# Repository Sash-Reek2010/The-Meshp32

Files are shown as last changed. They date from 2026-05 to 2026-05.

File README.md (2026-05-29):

# The Meshp32
An ESP32 based devboard who's main purpose is to run Meshtastic firmware! It has 22 pins broken out which can be used to attach an external screen and keyboard to transmit messages or even speakers for auditory output. It has a TP4056 so it can become a portable rechargable mestastic node in itself! It aslo features the SX126 as the LoRA board required for Meshtastic! In all, the components cost around 16 dollars in LCSC.

# The Devboard

## The Schematic
This schematic is made in KiCAD!

lora schematic

## The PCB
This PCB is also made in KiCAD!

Devboard 1

Devboard 2

## PCB View

Devboard 3

devboard 4

## Case

Case

The Meshp32 Case

## Try it out!

[KiCanvas Link](https://kicanvas.org/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)

## Meshtastic Firmware

https://github.com/meshtastic/meshtastic

## Thanks for reading :D -Sashreek!

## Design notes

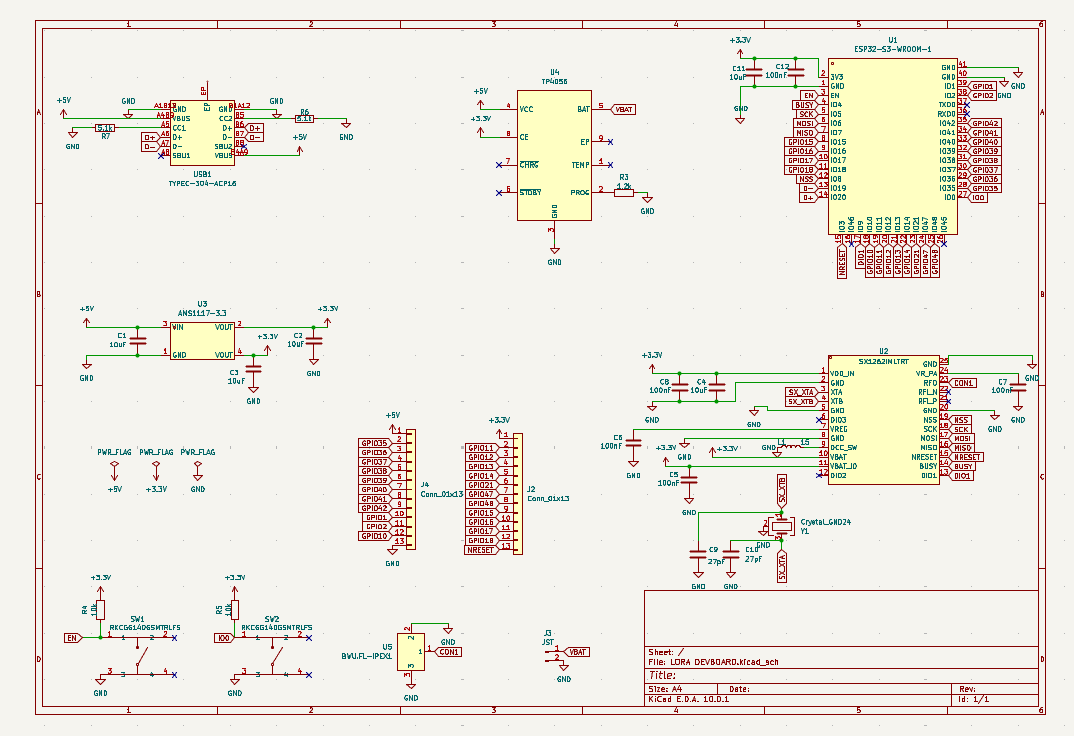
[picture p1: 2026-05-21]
Assets/PCB Schematic.png

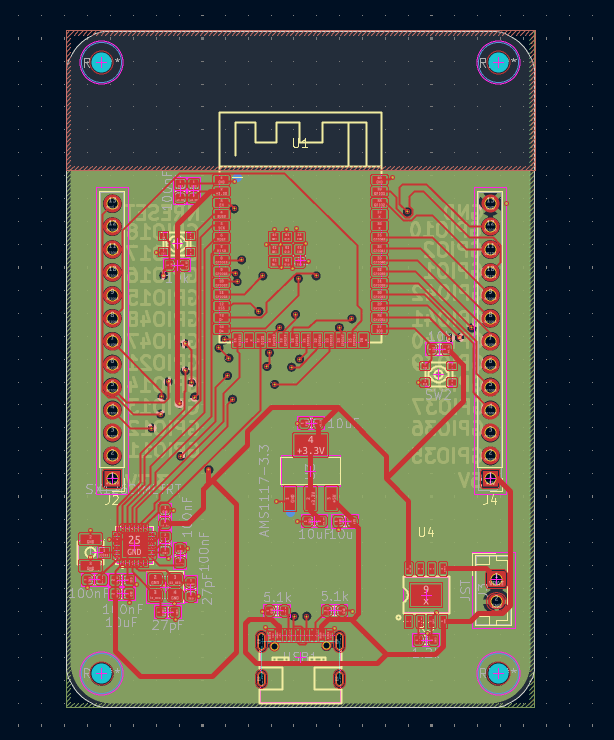
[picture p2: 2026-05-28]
Assets/Devboard 2.png

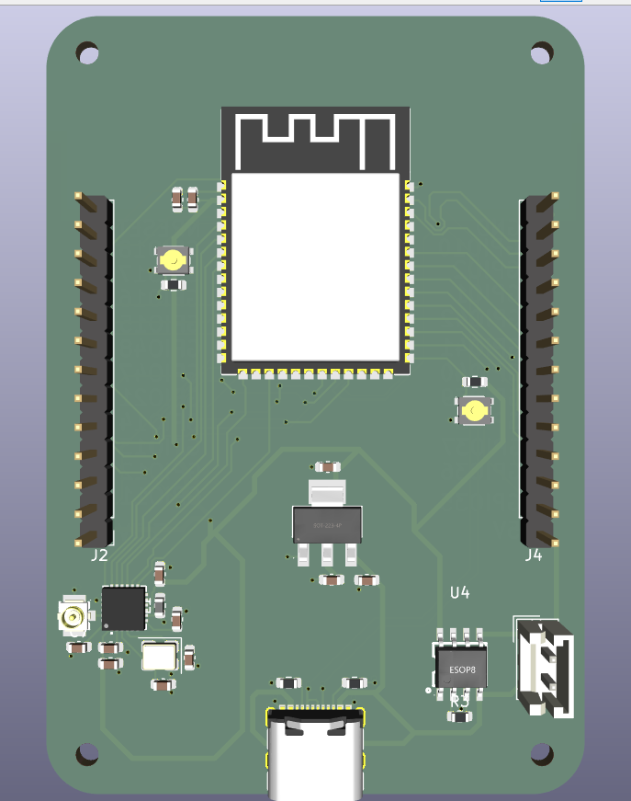
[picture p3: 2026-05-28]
Assets/Devboard 3.png

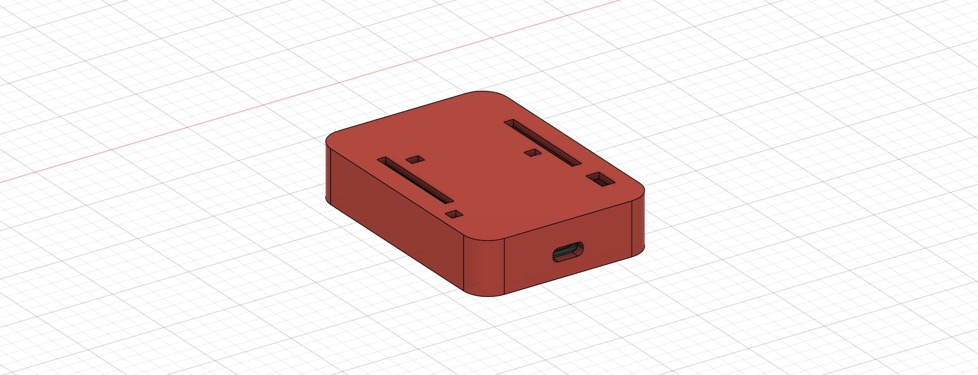
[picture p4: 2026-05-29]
Assets/The Meshp32 Case.png

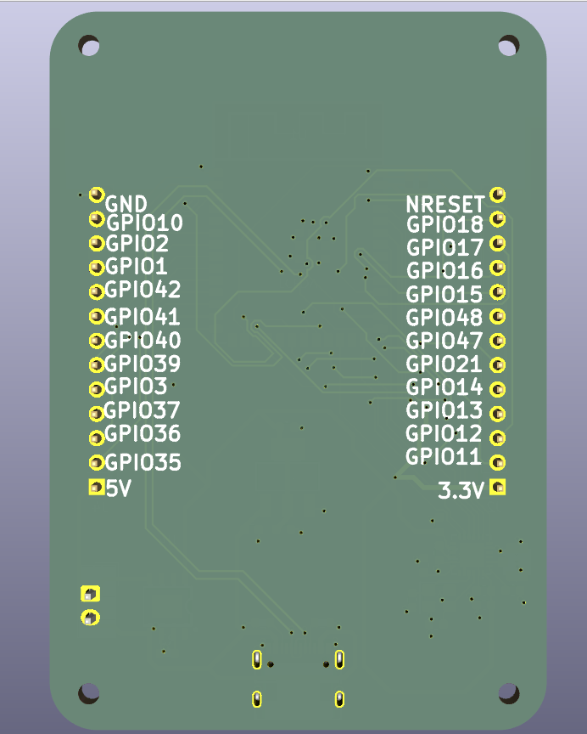
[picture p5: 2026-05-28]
Assets/devboard 4.png

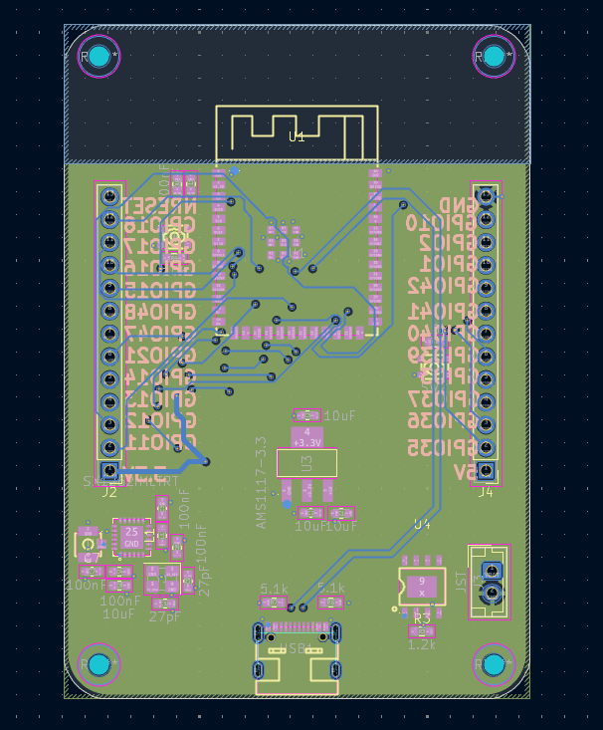
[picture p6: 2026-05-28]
Assets/Devboard 1.png

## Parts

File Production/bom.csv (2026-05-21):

Designator | Footprint | Quantity | Value | LCSC Part #
C1, C11, C2, C3, C4 | 0603 | 5 | 10uF
C10, C9 | 0603 | 2 | 27pF
C12, C5, C6, C7, C8 | 0603 | 5 | 100nF
J2, J4 | PinHeader_1x13_P2.54mm_Vertical | 2 | Conn_01x13
J3 | JST_EH_B2B-EH-A_1x02_P2.50mm_Vertical | 1 | JST
L1 | 0603 | 1 | 15
R3 | 0603 | 1 | 1.2k
R4, R5 | 0603 | 2 | 10k
R6, R7 | 0603 | 2 | 5.1k
SW1, SW2 | SW-SMD_4P-L3.0-W2.6-P1.80-LS3.5 | 2 | RKCGG140GSMTRLFS | C2927791
U1 | WIRELM-SMD_ESP32-S3-WROOM-1 | 1 | ESP32-S3-WROOM-1 | C2913205
U2 | QFN-24_L4.0-W4.0-P0.50-BL-EP2.6 | 1 | SX1262IMLTRT | C191341
U3 | SOT-223-3_L6.5-W3.4-P2.30-LS7.0-BR | 1 | AMS1117-3.3 | C6186
U4 | ESOP-8_L4.9-W3.9-P1.27-LS6.0-BL-EP | 1 | TP4056 | C16581
U5 | IPEX-SMD_BWIPX-1-001E | 1 | BWU.FL-IPEX1 | C5137195
USB1 | USB-C-SMD_TYPE-C-16P-1 | 1 | TYPEC-304-ACP16 | C2982555
Y1 | Crystal_SMD_3225-4Pin_3.2x2.5mm | 1 | Crystal_GND24

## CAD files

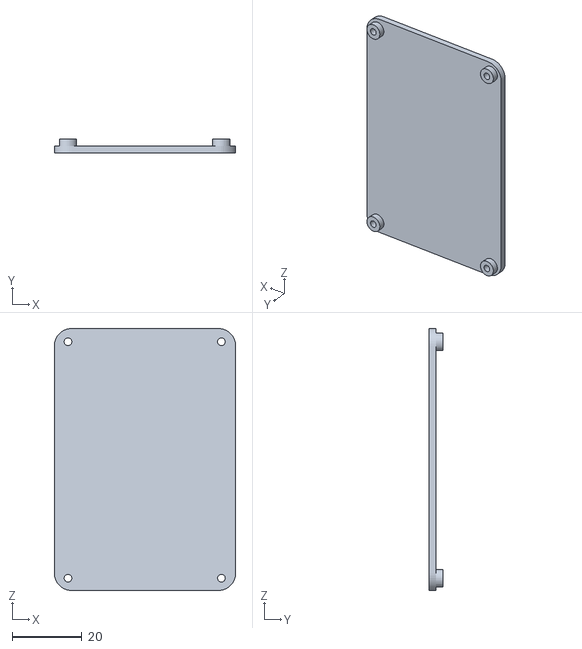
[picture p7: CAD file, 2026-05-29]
Production/Case Bottom.stl
51.9 x 4.00 x 75.0

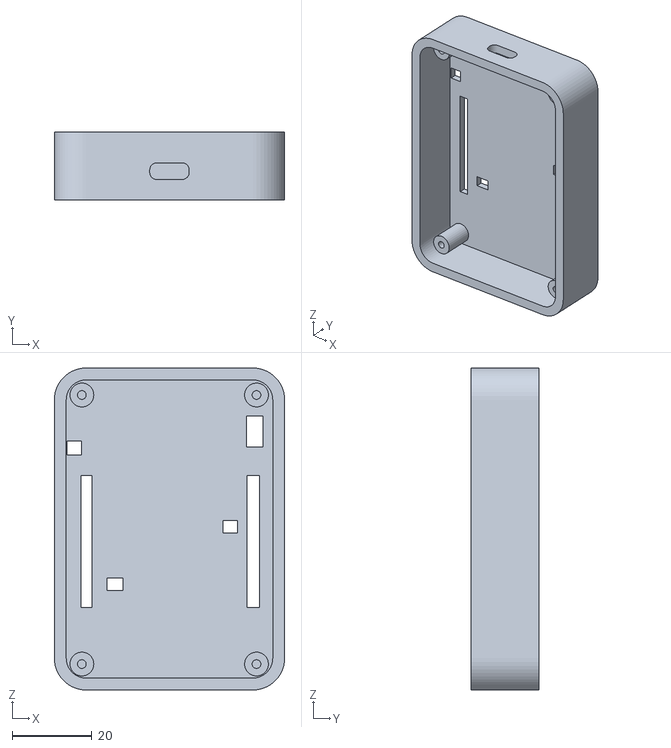
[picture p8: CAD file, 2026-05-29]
Production/Case Top.stl
57.9 x 17.0 x 81.0

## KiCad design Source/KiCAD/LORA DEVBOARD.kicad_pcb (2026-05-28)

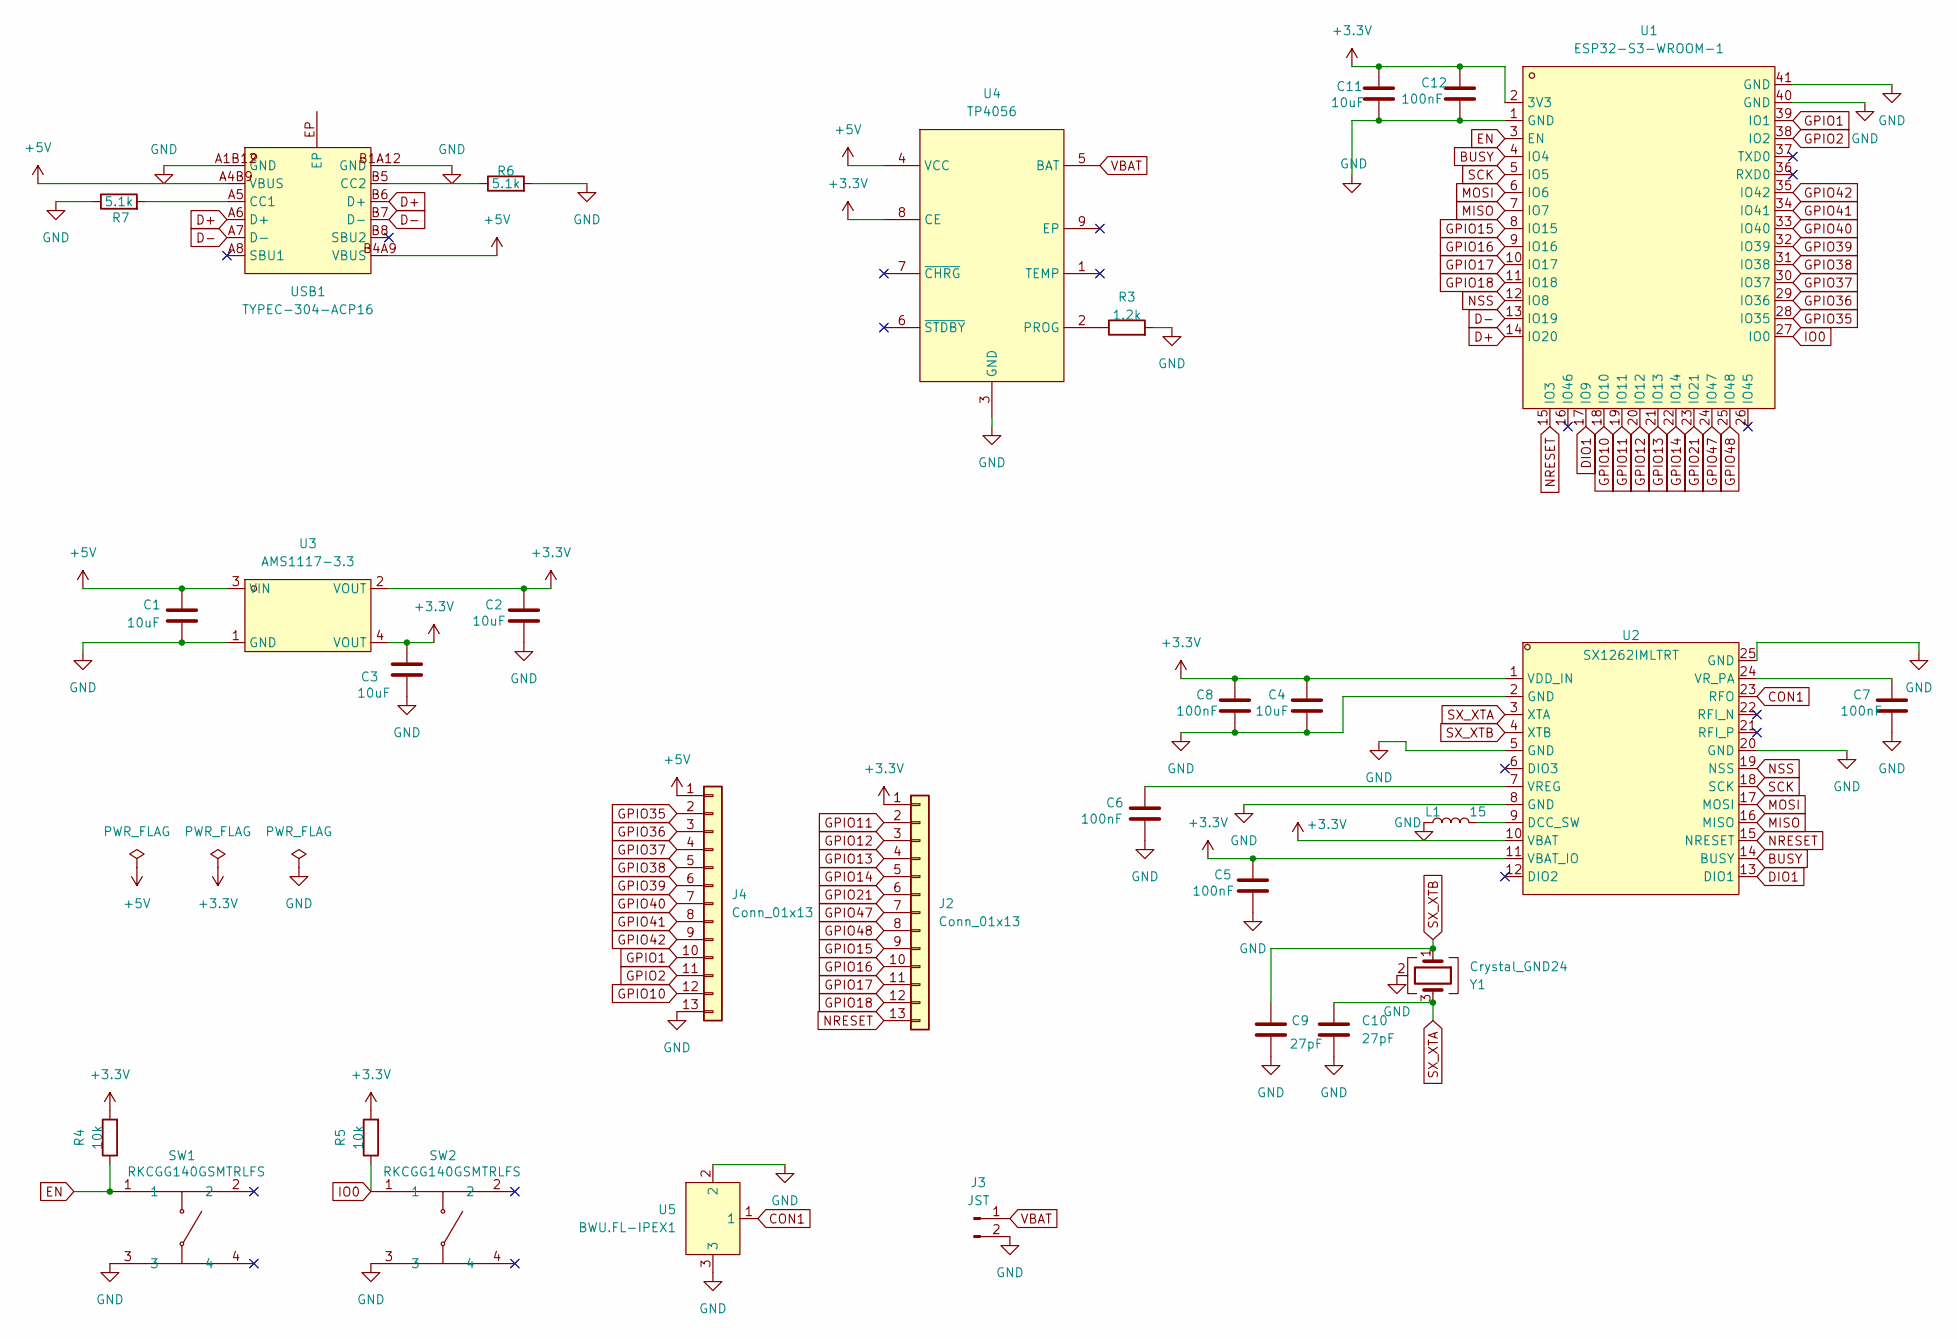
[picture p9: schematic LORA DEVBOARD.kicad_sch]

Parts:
C1, C2, C3, C4, C11: 10uF; C_0603_1608Metric
C5, C6, C7, C8, C12: 100nF; C_0603_1608Metric
C9, C10: 27pF; C_0603_1608Metric
J2, J4: Conn_01x13; PinHeader_1x13_P2.54mm_Vertical
J3: JST; JST_EH_B2B-EH-A_1x02_P2.50mm_Vertical
L1: 15; L_0603_1608Metric
R3: 1.2k; R_0603_1608Metric
R4, R5: 10k; R_0603_1608Metric
R6, R7: 5.1k; R_0603_1608Metric
SW1, SW2: RKCGG140GSMTRLFS; SW-SMD_4P-L3.0-W2.6-P1.80-LS3.5; MPN RKCGG140GSMTRLFS; LCSC Part C2927791
U1: ESP32-S3-WROOM-1; WIRELM-SMD_ESP32-S3-WROOM-1; MPN ESP32-S3-WROOM-1-N16R2; LCSC Part C2913205
U2: SX1262IMLTRT; QFN-24_L4.0-W4.0-P0.50-BL-EP2.6; MPN SX1262IMLTRT; LCSC Part C191341
U3: AMS1117-3.3; SOT-223-3_L6.5-W3.4-P2.30-LS7.0-BR; MPN AMS1117-3.3; LCSC Part C6186
U4: TP4056; ESOP-8_L4.9-W3.9-P1.27-LS6.0-BL-EP; MPN TP4056-42-ESOP8; LCSC Part C16581
U5: BWU.FL-IPEX1; IPEX-SMD_BWIPX-1-001E; MPN BWU.FL-IPEX1; LCSC Part C5137195
USB1: TYPEC-304-ACP16; USB-C-SMD_TYPE-C-16P-1; MPN TYPEC-304-ACP16; LCSC Part C2982555
Y1: Crystal_GND24; Crystal_SMD_3225-4Pin_3.2x2.5mm

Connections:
+3.3V: C2.2, C3.2, C4.2, C5.2, C8.2, C11.2, C12.2, J2.1, R4.2, R5.2, U1.2 (3V3), U2.1 (VDD_IN), U2.10 (VBAT), U2.11 (VBAT_IO), U3.2 (VOUT), U3.4 (VOUT), U4.8 (CE)
+5V: C1.2, J4.1, U3.3 (VIN), U4.4 (VCC), USB1.A4B9 (VBUS), USB1.B4A9 (VBUS)
BUSY: U1.4 (IO4), U2.14 (BUSY)
CON1: U2.23 (RFO), U5.1
D+: U1.14 (IO20), USB1.A6 (D+), USB1.B6 (D+)
D-: U1.13 (IO19), USB1.A7 (D-), USB1.B7 (D-)
DIO1: U1.17 (IO9), U2.13 (DIO1)
EN: R4.1, SW1.1, U1.3 (EN)
GND: C1.1, C2.1, C3.1, C4.1, C5.1, C6.1, C7.1, C8.1, C9.2, C10.2, C11.1, C12.1, J3.2, J4.13, L1.1, R3.2, R6.2, R7.1, SW1.3, SW2.3, U1.1 (GND), U1.40 (GND), U1.41 (GND), U2.2 (GND), U2.5 (GND), U2.8 (GND), U2.20 (GND), U2.25 (GND), U3.1 (GND), U4.3 (GND), U5.2, U5.3, USB1.A1B12 (GND), USB1.B1A12 (GND), Y1.2 (G), Y1.4 (G)
GPIO1: J4.10, U1.39 (IO1)
GPIO2: J4.11, U1.38 (IO2)
GPIO10: J4.12, U1.18 (IO10)
GPIO11: J2.2, U1.19 (IO11)
GPIO12: J2.3, U1.20 (IO12)
GPIO13: J2.4, U1.21 (IO13)
GPIO14: J2.5, U1.22 (IO14)
GPIO15: J2.9, U1.8 (IO15)
GPIO16: J2.10, U1.9 (IO16)
GPIO17: J2.11, U1.10 (IO17)
GPIO18: J2.12, U1.11 (IO18)
GPIO21: J2.6, U1.23 (IO21)
GPIO35: J4.2, U1.28 (IO35)
GPIO36: J4.3, U1.29 (IO36)
GPIO37: J4.4, U1.30 (IO37)
GPIO38: J4.5, U1.31 (IO38)
GPIO39: J4.6, U1.32 (IO39)
GPIO40: J4.7, U1.33 (IO40)
GPIO41: J4.8, U1.34 (IO41)
GPIO42: J4.9, U1.35 (IO42)
GPIO47: J2.7, U1.24 (IO47)
GPIO48: J2.8, U1.25 (IO48)
IO0: R5.1, SW2.1, U1.27 (IO0)
MISO: U1.7 (IO7), U2.16 (MISO)
MOSI: U1.6 (IO6), U2.17 (MOSI)
NRESET: J2.13, U1.15 (IO3), U2.15 (NRESET)
NSS: U1.12 (IO8), U2.19 (NSS)
unnamed: L1.2, U2.9 (DCC_SW)
unnamed: C6.2, U2.7 (VREG)
unnamed: C7.2, U2.24 (VR_PA)
unnamed: R3.1, U4.2 (PROG)
unnamed: R7.2, USB1.A5 (CC1)
unnamed: R6.1, USB1.B5 (CC2)
SCK: U1.5 (IO5), U2.18 (SCK)
SX_XTA: C10.1, U2.3 (XTA), Y1.3
SX_XTB: C9.1, U2.4 (XTB), Y1.1
VBAT: J3.1, U4.5 (BAT)

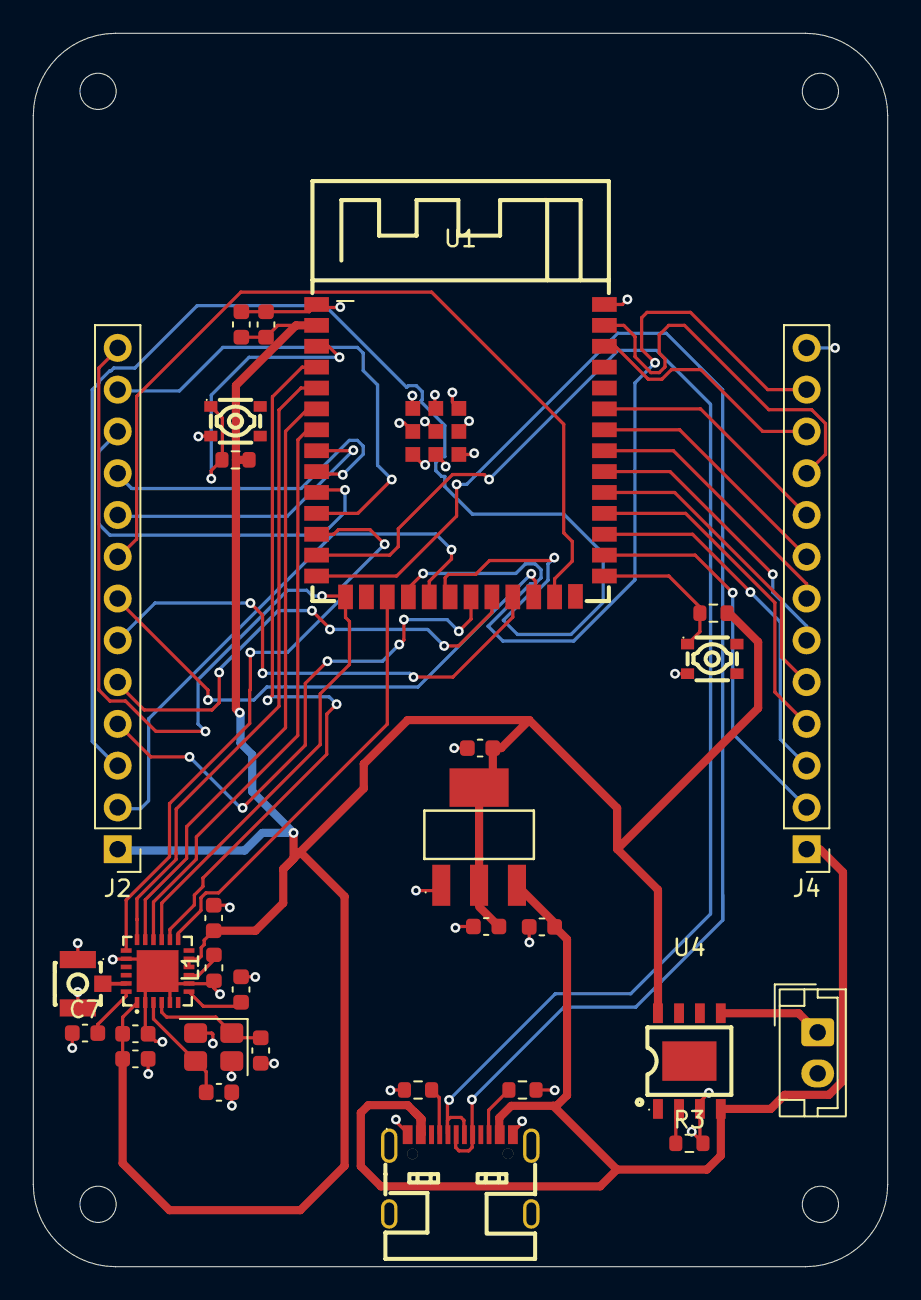
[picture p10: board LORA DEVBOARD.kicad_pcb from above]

Board: 4 copper layers, 51.9 x 75.0 mm, 30 parts (0 on the bottom side), 46 nets.

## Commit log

2026-05-16 Add Case
    [Case Bottom .stl, Case Top.stl]
2026-05-21 Update PCB
    [LORA DEVBOARD.kicad_pcb, LORA DEVBOARD.kicad_sch, bom.csv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]
2026-05-21 Rearrange Files
    [LORA DEVBOARD.kicad_pcb, LORA DEVBOARD.kicad_sch]
2026-05-21 Update Case
    [Case Top.stl]
2026-05-28 Replace Files
    [Case Bottom .stl, Case Top.stl, LORA DEVBOARD.kicad_pcb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]
